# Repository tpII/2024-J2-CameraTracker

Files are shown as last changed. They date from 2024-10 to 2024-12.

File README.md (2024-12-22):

# 2024-J2-CameraTracker

---

<div align="center">
  <table>
    <tr>
      <td>GIF del Robot en Acción</td>
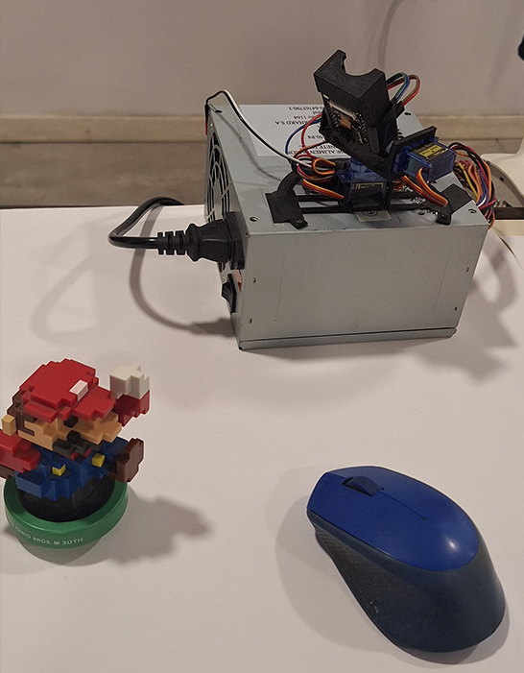
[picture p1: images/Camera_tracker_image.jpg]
Hardware del Proyecto
      <td></td>
    </tr>
  </table>
</div>

---

## Descripción

El proyecto **Camera Tracker** es un sistema de seguimiento de objetos que utiliza una cámara ESP32-CAM montada en una torreta. El sistema es capaz de reconocer y seguir objetos utilizando un modelo de aprendizaje automático optimizado, implementado en la plataforma Edge Impulse.

---

## Documentación

Consulta la [documentación del proyecto](https://github.com/tpII/2024-J2-CameraTracker/blob/master/docs/Camera%20Tracker%20-%20Project%20Overview%20%5BSP%5D.pdf) para obtener una visión más detallada de los objetivos, implementación y resultados del sistema.

---

## Contenido

- [Características](#características)
- [Hardware](#hardware)
- [Reconocimiento de Objetos](#reconocimiento-de-objetos)
- [Configuración del Entorno](#configuración-del-entorno)
- [Licencia](#licencia)

---

## Características

- Seguimiento de objetos.
- Integración de hardware utilizando ESP32-CAM y servomotores.
- Modelo de reconocimiento de objetos entrenado con Edge Impulse.
- Interfaz web para monitoreo y configuración.

---

## Hardware

El hardware del proyecto se basa en las siguientes etapas:

1. **Medición de Componentes**: Se realizan mediciones detalladas de los componentes.
2. **Diseño Inicial**: Se elabora un boceto preliminar a mano alzada.
3. **Diseño 3D**: Se utiliza Autodesk Fusion 360 para diseñar las piezas y exportarlas en formato `.stl` para impresión 3D.
4. **Prototipado**: Se desarrollan varias versiones del prototipo para optimizar el equilibrio y funcionalidad del sistema.

---

## Reconocimiento de Objetos

El reconocimiento de objetos se realiza mediante el uso de **Edge Impulse**, donde se entrena un modelo para identificar diferentes elementos. El proceso incluye:

1. **Captura de Imágenes**: Se toman aproximadamente 700 fotos de cada objeto con buena iluminación y fondo uniforme.
2. **Etiquetado**: Las imágenes se etiquetan manualmente en la plataforma Edge Impulse.
3. **Generación de Features**: Se especifica el "color depth" (escala de grises o RGB).
4. **Entrenamiento del Modelo**: Se ajusta el modelo y se realiza el entrenamiento.
5. **Evaluación**: Se utiliza la matriz de confusión para analizar el rendimiento del modelo y determinar posibles mejoras.

---

## Configuración del Entorno

### Instalación de Manejadores de Placa

1. Abre el IDE de Arduino.
2. Ve a **Archivo > Preferencias** y añade la URL para el ESP32 en "Gestor de URLs Adicionales":
   ```
   https://dl.espressif.com/dl/package_esp32_index.json
   ```
3. Dirígete a **Herramientas > Placa > Gestor de Placas** y busca e instala las siguientes versiones:
   - **Arduino AVR Boards**: Versión 1.8.6.
   - **ESP32 by Espressif Systems**: Versión 2.0.5.

### Configuración de la Placa

1. Selecciona **AI-Thinker ESP32-CAM** en el menú de placas.
2. Configura el puerto correspondiente al dispositivo conectado.

### Instalación de Bibliotecas

1. Abre el **Library Manager** desde el IDE de Arduino.
2. Instala las siguientes bibliotecas:
   - **ESP32Servo**: Versión 3.0.5.
   - **FreeRTOS** (incluida por defecto):
     ```cpp
     #include <freertos/FreeRTOS.h>
     #include <freertos/semphr.h>
     ```
   - **WiFi** y **esp_http_server** (incluidas por defecto):
     ```cpp
     #include <WiFi.h>
     #include "esp_http_server.h"
     ```
   - **Arduino Core** (incluida por defecto):
     ```cpp
     #include "Arduino.h"
     ```
3. Importa manualmente la biblioteca de inferencia generada por Edge Impulse:
   - Descarga el archivo `.zip` desde Edge Impulse.
   - Usa la opción **Sketch > Incluir Biblioteca > Añadir biblioteca .ZIP**.
   - Incluye los siguientes archivos en tu proyecto:
     ```cpp
     #include <lapor-project-1_inferencing.h>
     #include "edge-impulse-sdk/dsp/image/image.hpp"
     ```
4. Asegúrate de tener las bibliotecas para dibujado de bounding boxes:
   ```cpp
   #include "img_converters.h"
   #include "fb_gfx.h"
   ```

### Clonación del Repositorio

Clona el repositorio del proyecto para acceder a todo el código fuente y configuración:
```bash
git clone https://github.com/tpII/2024-J2-CameraTracker.git
```

---

## Licencia

Este proyecto está bajo la Licencia GPL 3.0. Consulta el archivo `LICENSE` para más detalles.

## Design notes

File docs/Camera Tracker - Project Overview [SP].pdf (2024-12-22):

# Taller de Proyecto II

## Informe Final - J2

## Camera Tracker

Grupo de Desarrollo

- Deluca, Tadeo - 02655/1
- La Porta, Franco - 02307/2
- Reverte Adriel - 02614/1

Índice

### 1. Descripción General del Proyecto

### 1.1. Introducción

El proyecto Camera Tracker se desarrolló con el objetivo de implementar un sistema de seguimiento automático de objetos mediante un ESP32-Cam y una torreta con movimiento en dos ejes. Durante las etapas iniciales y medias de desarrollo, se abordaron aspectos clave de hardware, firmware e inteligencia artificial para lograr los objetivos establecidos.

En el transcurso del desarrollo, se enfrentaron desafíos técnicos, como problemas eléctricos y fallas en componentes de hardware, que requirieron soluciones iterativas. Estos ajustes permitieron entregar un sistema funcional capaz de realizar el seguimiento de objetos para el cual fue entrenado, cumpliendo los objetivos primarios propuestos originalmente.

### 1.2. Objetivos del Proyecto

Objetivos Iniciales

El proyecto fue diseñado para cumplir los siguientes objetivos principales, los cuales fueron cumplidos::

1. Captura y transmisión de video: Implementar un sistema de streaming en vivo desde la cámara a través de una interfaz web.
2. Detección y seguimiento de objetos: Utilizar un modelo de inteligencia artificial para detectar y rastrear objetos.
3. Control de la torreta: Ajustar dos servomotores para alinear la cámara con el objeto detectado, ofreciendo movimiento en dos ejes.
4. Interacción desde la interfaz web: Permitir la selección del objeto a rastrear entre dos opciones disponibles (una estatuilla de Super Mario y un mouse azul) y activar/desactivar el streaming de video.

Cambios y Modificaciones

1. Modificaciones sugeridas por la cátedra:
- Fuente de alimentación externa: Debido a problemas de consumo eléctrico al conectar el ESP32-Cam y los dos servos, se utilizó una fuente de alimentación externa proporcionada por la cátedra. Esto solucionó los problemas de insuficiencia energética y permitió un funcionamiento estable.

2. Cambios derivados de decisiones de desarrollo:
- Reemplazo de hardware defectuoso: Se identificaron fallas en los servomotores SG90 y en el flex de la cámara del ESP32-Cam. Estas fallas llevaron a la sustitución de componentes dañados, incluyendo la compra de una nueva ESP32-Cam.
3. Modificaciones técnicas propias:
- Botones para selección de objetos: Se agregó a la interfaz web la funcionalidad para permitir al usuario seleccionar entre dos objetos predefinidos (Super Mario y el Mouse) como objetivo del seguimiento.
- Reestilizado de la interfaz web: Se realizaron mejoras visuales en la interfaz web.
- Dibujado de la bounding box: Se implementó una funcionalidad que dibuja un marcador visual (bounding box) alrededor del objeto detectado en la transmisión de video.
- Optimización de la lógica de movimiento de servos:
- Cambio en la lógica de movimiento: La lógica inicial, basada en un mapeo directo entre las coordenadas de píxeles en la imagen y los ángulos de los servos, fue reemplazada. En su lugar, se adoptó un enfoque de movimiento en pasos de ángulos discretos hacia la dirección del objeto detectado. Este cambio permitió que el movimiento fuera más suave y controlado, lo que redujo vibraciones y aumentó la precisión aparente del seguimiento.

Objetivos no Cumplidos

Los objetivos secundarios relacionados con la implementación de conexión a servicios en la nube y medidas avanzadas de seguridad (autenticación mediante formulario y protocolo HTTPS) no pudieron ser completados debido a limitaciones de tiempo y retrasos asociadas al hardware del proyecto.

### 2. Presentación Esquemática del Proyecto

En esta sección presentaremos una actualización completa del proyecto tal como se entrega.

El siguiente gráfico ilustra el flujo desde la captura de una fotografía hasta el procesamiento e inferencia de los datos obtenidos.

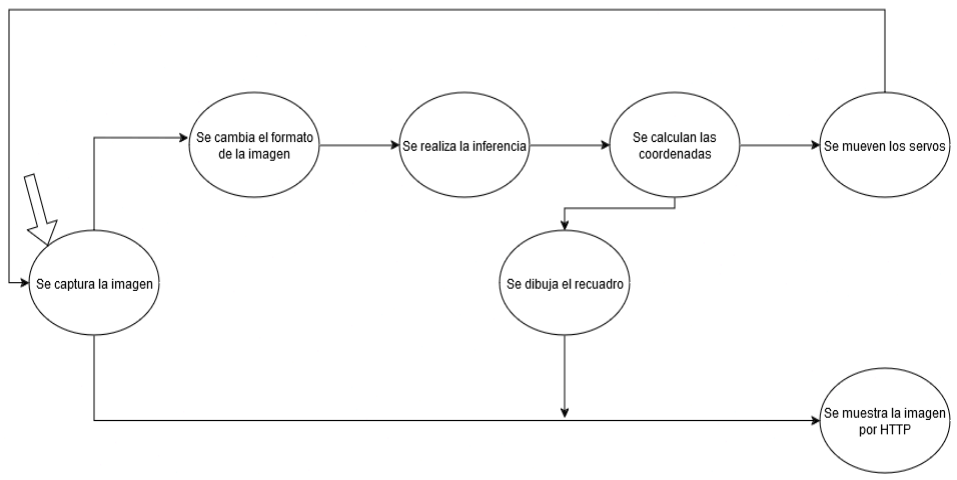
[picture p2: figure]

Figura 1. Diagrama de flujo captura de imagen

Se observa cómo la imagen capturada pasa por un cambio de formato para ser utilizada en la inferencia. Luego, si se identifica un objeto seleccionado con una confianza superior al 85%, se realiza la identificación, se marca su posición en la imagen con un recuadro, y se envían señales a los servomotores para ajustar la dirección de la cámara hacia el objeto. Finalmente, la última imagen procesada se transmite en formato JPG al servidor HTTP.

A continuación, se presenta el esquema gráfico que describe la versión estática del sistema desarrollado.

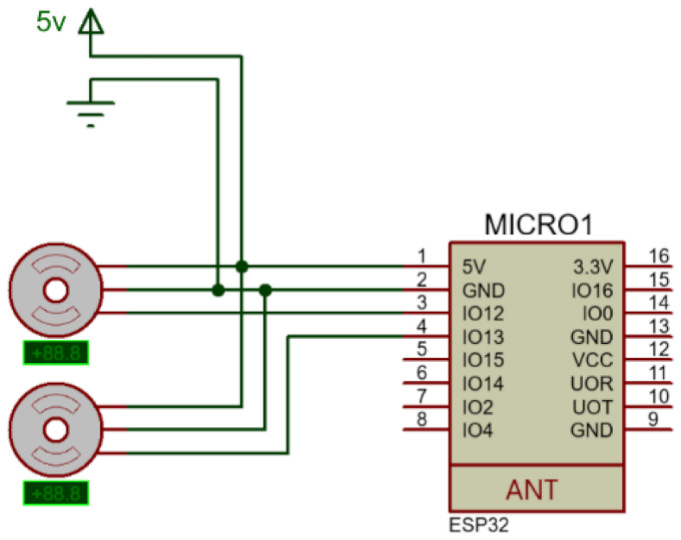
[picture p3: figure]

Figura 2. Esquema gráfico físico

En este diagrama, se identifica al ESP32-CAM como el componente principal del sistema, programado mediante un programador USB y alimentado por una fuente de computadora a través de un módulo step-down, que asegura el suministro de energía adecuado. Además, se muestra cómo el ESP32-CAM controla dos servomotores SG90, responsables de permitir el movimiento de la cámara para la función de seguimiento de objetos. Cada módulo y conexión se detalla de manera explícita para facilitar la comprensión del diseño y su implementación.

### 3. Estructura del proyecto CameraTracker

El proyecto se organiza en una estructura jerárquica que incluye los archivos principales y las librerías necesarias para implementar las funcionalidades del sistema. A continuación, se describe la estructura y el contenido de cada componente.

### 3.1. Estructura de archivos

CameraTracker/
├── CameraTracker.ino
├── camera_config.h
├── servo_control.h
├── web_server.h
└── libraries/
├── ESP32Servo
└── lapor-project-1_inferencing

### 3.2. Descripción de los archivos principales

### 1. Archivo camera_config.h

Este archivo define las configuraciones del módulo de cámara AI-Thinker ESP32-CAM, incluyendo los pines GPIO y los parámetros constantes para la captura de imágenes.

Contenido principal:

- Definición de pines GPIO utilizados por la cámara.
- Configuración de las dimensiones del búfer de imágenes capturadas.
- Inclusión de librerías esenciales como esp_camera.h y fb_gfx.h para la configuración de la cámara y manipulación de imágenes..

### 2. Archivo servo_control.h

Define los pines GPIO asociados con los servos utilizados para el control del movimiento de la cámara y emplea la librería ESP32Servo para gestionar su funcionamiento.

### 3. Archivo web_server.h

Gestiona la configuración y las funcionalidades del servidor web.

Contenido principal:

- Inclusión de librerías esenciales como WiFi.h y esp_http_server.h.
- Configuración de constantes para el manejo del flujo de transmisión, como PART_BOUNDARY.

### 4. Archivo CameraTracker.ino

Integra la lógica central del proyecto, incluyendo la inicialización de los componentes, la ejecución de las funciones principales y la interacción entre las diferentes partes del sistema.

Funciones principales:

- setup():
- Inicializa la cámara, la conexión Wi-Fi, los servos y las tareas para el streaming y la inferencia.
- Configura el servidor web.
- loop():
- Vacío debido a que las operaciones continuas son gestionadas por las tareas paralelas inferenceLoop y streamLoop.
- inferenceLoop():
- Ejecuta las inferencias sobre las imágenes capturadas.
- Ajusta la posición de los servos según los resultados de la inferencia.
- streamLoop():
- Administra el estado del servidor web y lo reinicia si es necesario.

Otras funciones relevantes

### 1. Inicialización y control de la cámara

- ei_camera_init(): Configura y activa la cámara.
- ei_camera_deinit(): Libera los recursos asociados a la cámara.

- ei_camera_capture(uint32_t img_width, uint32_t img_height, uint8_t *out_buf): Captura una imagen con las dimensiones especificadas por el modelo que realiza la inferencia y la almacena en el búfer proporcionado.

### 2. Configuración del servidor web

- startCameraServer(): Configura y lanza el servidor web para la transmisión de imágenes.
- index_handler(httpd_req_t *req): Maneja las solicitudes a la página de inicio (/) y proporciona una respuesta HTML.
- select_handler(httpd_req_t *req): Procesa solicitudes HTTP relacionadas con la selección de objetos para rastrear.
- stream_handler(httpd_req_t *req): Maneja el flujo continuo de video (streaming).

### 3. Tareas concurrentes

- inferenceLoop(void *parameter):
- Ejecuta inferencias de clasificación sobre imágenes capturadas usando un modelo de Edge Impulse.
- Ajusta la posición de los servos con base en los resultados de la inferencia.
- streamLoop(void *parameter): Supervisa el servidor web y lo reinicia si deja de funcionar.

### 3.3. Configuración de software y dependencias del proyecto

### 3.3.1. Configuración de manejadores de placa en el Arduino IDE

Manejadores de Placa Instalados

Para el desarrollo del proyecto, se instalaron los siguientes manejadores de placa a través del Board Manager del IDE de Arduino:

- Arduino AVR Boards: Versión 1.8.6, utilizada para gestionar placas basadas en microcontroladores AVR en proyectos generales.
- ESP32 by Espressif Systems: Versión 2.0.5. Esta versión fue seleccionada por su compatibilidad con las bibliotecas utilizadas en el proyecto, como la biblioteca de inferencia generada por Edge Impulse y la biblioteca WiFi.h. No se utilizó la versión más reciente debido a problemas de compatibilidad.

### 3.3.2. Configuración de la Placa

La generación y carga del binario se realizó configurando la placa como "AI-Thinker ESP32-CAM", correspondiente al módulo de hardware utilizado en el proyecto. Esta configuración fue seleccionada desde el menú de puertos del IDE, asegurando que los parámetros de hardware coincidan con los requisitos del módulo.

### 3.3.3. Bibliotecas utilizadas en el proyecto

Bibliotecas instaladas mediante el Library Manager

El proyecto requiere la instalación de bibliotecas adicionales que no están incluidas de forma nativa en el IDE de Arduino. Estas bibliotecas deben instalarse a través del Library Manager..

- ESP32Servo: Versión 3.0.5, desarrollada por Kevin Harrington. Esta biblioteca permite el control de servomotores utilizando señales PWM generadas por el ESP32.

Bibliotecas nativas utilizadas

El proyecto también emplea bibliotecas que ya están incluidas de manera predeterminada en el IDE de Arduino o que no requieren instalación adicional. Estas incluyen:

FreeRTOS
#include <freertos/FreeRTOS.h>

#include <freertos/semphr.h>

- Utilizada para la concurrencia y la gestión de tareas en el ESP32, permitiendo implementar semáforos para la sincronización entre tareas.

WiFi y esp_http_server:
#include <WiFi.h>

#include "esp_http_server.h"

- Estas bibliotecas son esenciales para la configuración y operación del servidor web.

Arduino Core:
#include "Arduino.h"

- Incluye funcionalidades básicas y esenciales para la programación y ejecución en plataformas Arduino.

Bibliotecas externas requeridas

Además de las bibliotecas mencionadas, se utilizaron otras librerías específicas que deben ser incluidas manualmente en el proyecto:

Biblioteca de Inferencia Generada por Edge Impulse:

#include <lapor-project-1_inferencing.h>

#include "edge-impulse-sdk/dsp/image/image.hpp"

- Esta biblioteca es generada al exportar el modelo desde Edge Impulse en formato compatible con el IDE de Arduino. Se importa como archivo comprimido .zip y debe ser incluida en el proyecto a través de la opción "Añadir biblioteca .ZIP" en el IDE. Permite realizar inferencias utilizando el modelo previamente entrenado.

Bibliotecas para Dibujado de la Bounding Box:

#include "img_converters.h"

#include "fb_gfx.h"

- Estas bibliotecas son necesarias para procesar y renderizar elementos gráficos, como la bounding box, sobre las imágenes capturadas.

### 3.4. Herramientas de desarrollo y control de versiones

El proyecto utilizó Git para control de versiones y GitHub como repositorio online, facilitando la colaboración y el seguimiento de cambios. El desarrollo se realizó en el Arduino IDE.

### 3.5. Caso de uso del proyecto

En el siguiente diagrama de secuencia se presenta el caso completo que ocurre cuando un usuario selecciona uno de los objetos disponibles para ser identificado. El diagrama detalla todas las etapas del proceso, comenzando desde la inicialización del servidor web, encargado de gestionar las interacciones con el sistema, hasta la creación del recuadro que destaca el objeto identificado en la imagen procesada. Además, se incluye el control y ajuste de los servomotores, que permiten al sistema ajustar dinámicamente la posición de la cámara.

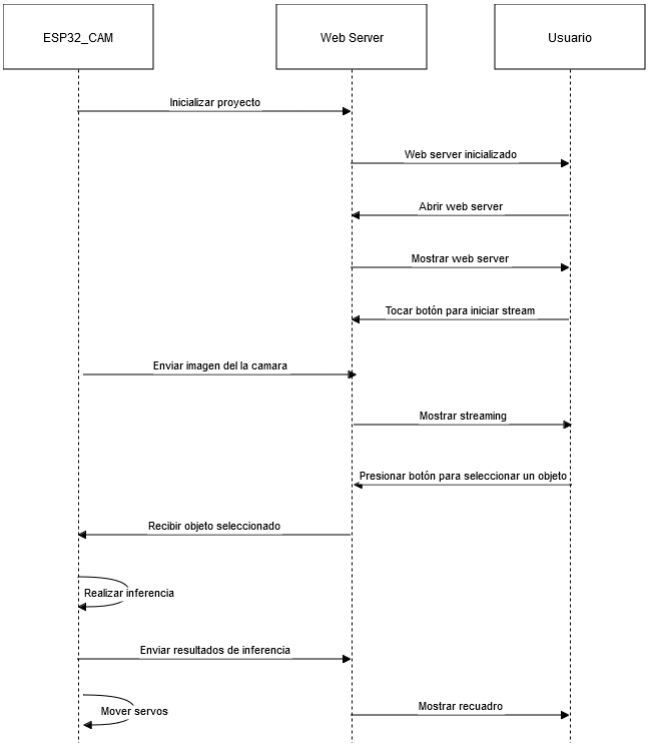
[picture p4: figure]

Figura 3. Diagrama de secuencia selección de objetos

### 4. Documentación Relacionada

### 4.1. Imágenes

En la primera imagen se muestra la interfaz web desarrollada para el proyecto, destacando las funcionalidades implementadas.

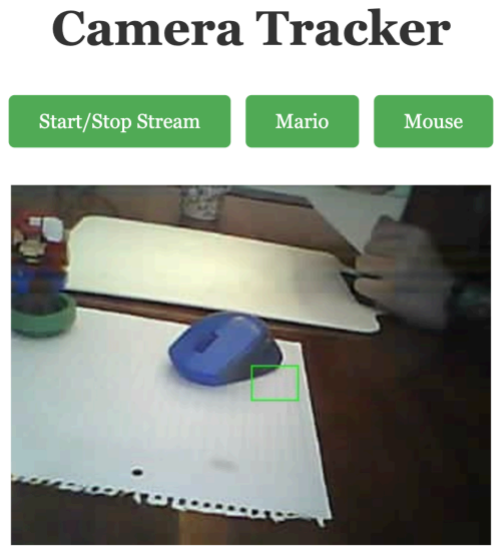
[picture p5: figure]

Figura 4. Imagen Web Server

En las siguientes imágenes se puede apreciar el aspecto físico del sistema, incluyendo la estructura completa y los servomotores encargados de controlar el movimiento de la cámara.

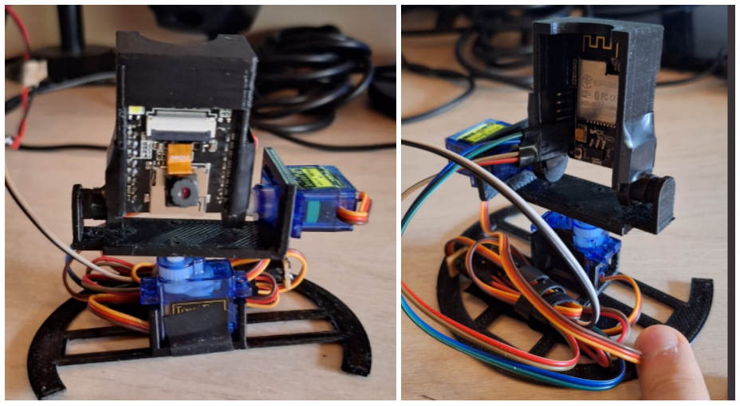
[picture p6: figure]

Figura 5. Imagen estructura con servos

### 4.2 Vídeos

Los vídeos relacionados con el proyecto están disponibles en la carpeta compartida, accesible a través del siguiente enlace: Carpeta de vídeos del proyecto (https://drive.google.com/drive/folders/1a-1BKRMfYGsX6SbaYhJ6COHhbvPWrK5T)

En el video titulado "Camera Tracker video de muestra", se presenta el proyecto en su totalidad, mostrando de manera clara y detallada su funcionamiento completo.

### 4.3 Enlaces Relevantes

- Bitácora del Proyecto: La bitácora de avances de cada integrante del grupo se encuentra actualizada hasta la fecha y está disponible en el siguiente enlace: Bitácora (https://github.com/tpII/2024-J2-CameraTracker/wiki/Bit%C3%A1cora)
- Código Fuente: El código fuente de todos los ejemplos desarrollados hasta el momento está disponible en GitHub: Repositorio en GitHub (https://github.com/tpII/2024-J2-CameraTracker)
- Carpeta Compartida del Proyecto: Todos los archivos de interés relacionados con el proyecto se encuentran en la carpeta compartida accesible a través del siguiente enlace: Carpeta del Proyecto (https://drive.google.com/drive/folders/1a-1BKRMfYGsX6SbaYhJ6COHhbvPWrK5T)

Apéndice A. Materiales y Presupuesto

En esta sección se detalla la lista completa y actualizada de los elementos de hardware necesarios para la construcción del proyecto Camera Tracker, diferenciando entre aquellos que fueron provistos por la cátedra y los que fueron adquiridos por los alumnos. Además, se incluyen los costos aproximados de cada uno de estos materiales, basados en precios obtenidos durante el período de desarrollo del proyecto. Cabe aclarar que no se consideran dentro de este presupuesto dispositivos adicionales como computadoras o teléfonos móviles.

### 1. Materiales Provistos por la Cátedra

La cátedra ha proporcionado varios componentes esenciales para la realización del proyecto, los cuales se detallan a continuación:

- ESP32-Cam + Programador: $19.980,90
Esp32 Cam Ov2640 + Placa Base Programador Esp32-cam-mb Hobb | MercadoLibre (https://articulo.mercadolibre.com.ar/MLA-1138395462-esp32-cam-ov2640-placa-base-programador-esp32-cam-mb-hobb-_JM)
- Servo SG90 (x2): $2.519 (c/u)
Mini Servo Tower Pro Sg90 9g Robotica Arduino Servomotor | MercadoLibre (https://articulo.mercadolibre.com.ar/MLA-903024303-mini-servo-tower-pro-sg90-9g-robotica-arduino-servomotor-_JM)
- Fuente de PC: $19.500,00
Lote 2 Fuentes Atx 24p+p4 400w 450w Usadas Garantia Congreso | MercadoLibre (https://articulo.mercadolibre.com.ar/MLA-934999936-lote-2-fuentes-atx-24pp4-400w-450w-usadas-garantia-congreso-_JM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)

Estos materiales fueron claves para la implementación inicial del sistema de seguimiento, especialmente para el control de la cámara y la alimentación de la misma.

### 2. Materiales Provistos por los Alumnos

A continuación, se detallan los materiales adquiridos directamente por los alumnos para complementar el proyecto, los cuales también fueron necesarios para el montaje y pruebas del sistema:

- Protoboard: $4.000,00
Placa Experimental Protoboard 830 Puntos Arduino Electronica | MercadoLibre (https://www.mercadolibre.com.ar/placa-experimental-protoboard-830-puntos-arduino-electronica/p/MLA27915857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)
- Cables Arduino:
Cables Para Protoboard Macho Macho 20 Cm X 40 Dupont Arduino | MercadoLibre (https://www.mercadolibre.com.ar/cables-para-protoboard-macho-macho-20-cm-x-40-dupont-arduino/p/MLA32489698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)
- Filamento PLA: $12.999,00
Filamento Pla Impresora 3d * G S T * 1,75mm 320mt X1 Kg Gst | MercadoLibre (https://articulo.mercadolibre.com.ar/MLA-829117078-filamento-pla-impresora-3d-g-s-t-175mm-320mt-x1-kg-gst-_JM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)
- Cable USB Micro: $2.798,00
Cable Usb Somostec Micro Trenzado Carga Rápida 3.1 A 1m F | MercadoLibre (https://articulo.mercadolibre.com.ar/MLA-1600964172-cable-usb-somostec-micro-trenzado-carga-rapida-31-a-1m-f-_JM)

### 3. Evaluación de Presupuesto y Materiales

En general, la mayoría de los materiales esenciales para la construcción y prueba del Camera Tracker fueron provistos por la cátedra, con excepción de algunos componentes auxiliares que fueron adquiridos por los alumnos. Aunque algunos materiales ya se encuentran disponibles, las pruebas y desarrollo del proyecto dependerá de la correcta implementación de estos y otros materiales que puedan ser necesarios a futuro.

La suma total de los componentes adquiridos hasta el momento asciende a:

- Materiales provistos por la cátedra: $44.520
- Materiales adquiridos por los alumnos: $19.800

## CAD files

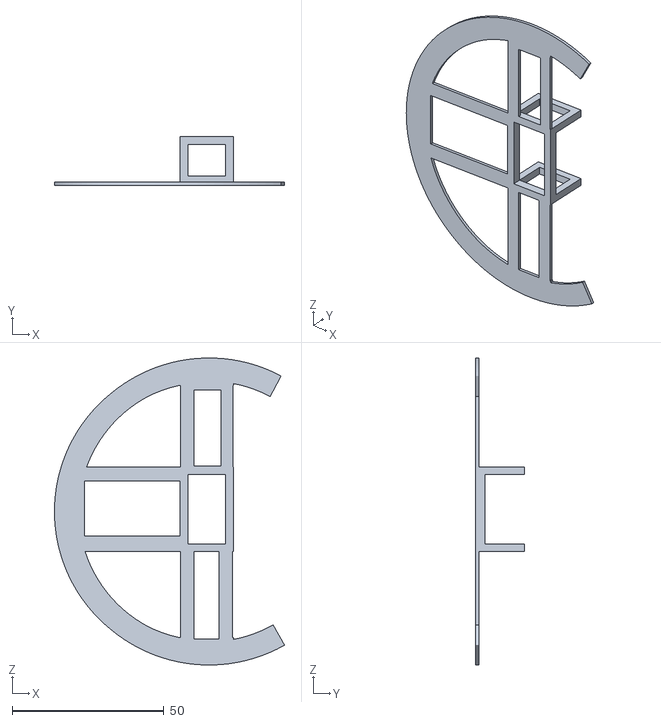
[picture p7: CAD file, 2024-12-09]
Diseños 3D/Estructura Final/Base.stl
75.9 x 16.0 x 101.3

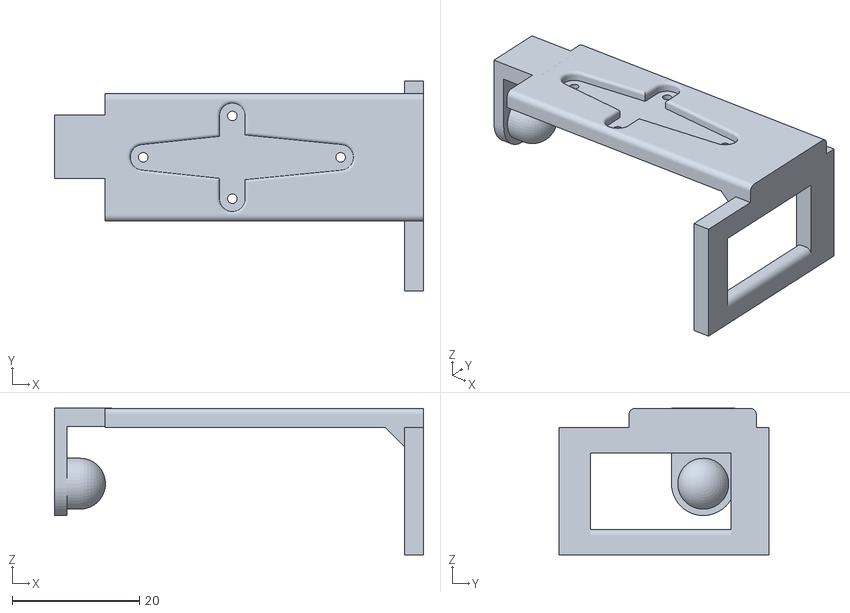
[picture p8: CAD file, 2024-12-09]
Diseños 3D/STLs/v7/Servo 5 v22.stl
57.9 x 33.0 x 23.0

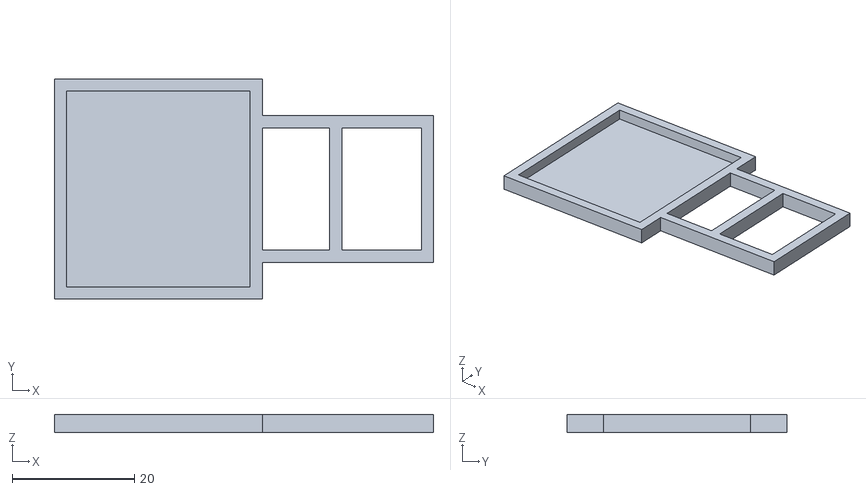
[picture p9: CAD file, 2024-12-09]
Diseños 3D/STLs/v6 (base)/base prueba.stl
62.0 x 36.0 x 3.00

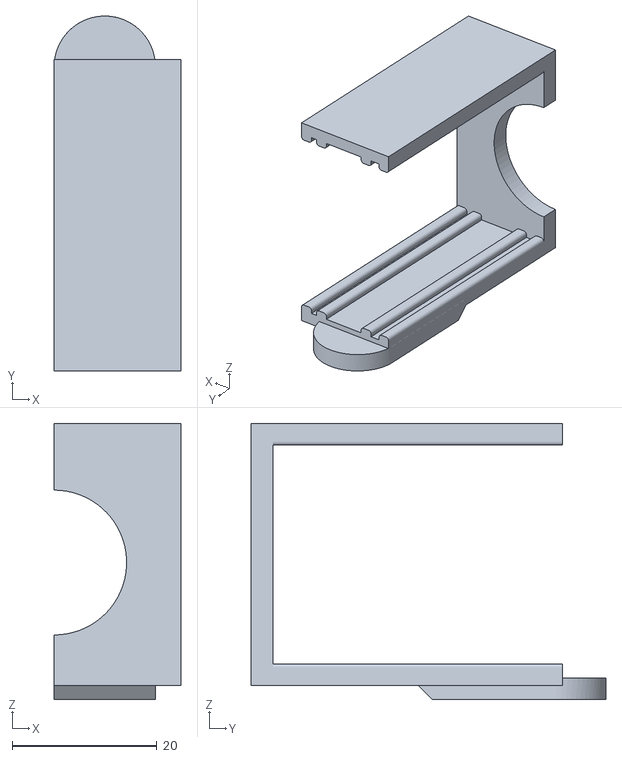
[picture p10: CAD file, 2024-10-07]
Diseños 3D/Estructura Final/pieza A.stl
17.5 x 49.0 x 38.1

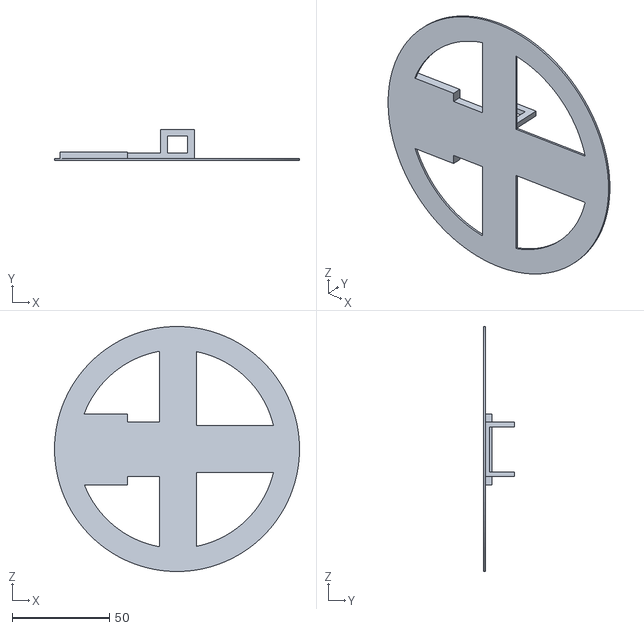
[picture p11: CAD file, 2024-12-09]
Diseños 3D/STLs/v6 (base)/base v16.stl
125.8 x 16.0 x 125.9

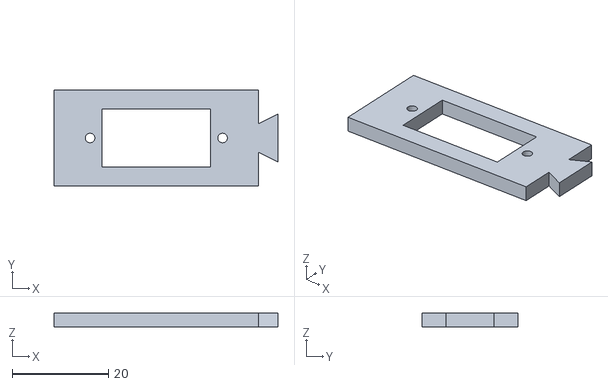
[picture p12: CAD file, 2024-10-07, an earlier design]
Diseños 3D/STLs/v1/Servo 1 v4.stl
46.5 x 20.0 x 3.00

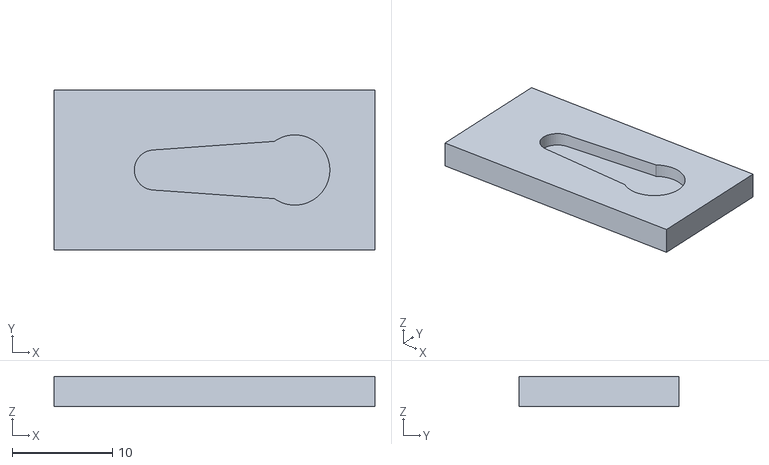
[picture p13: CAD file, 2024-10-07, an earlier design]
Diseños 3D/STLs/v2/Servo 4 v4.stl
32.0 x 16.0 x 3.00

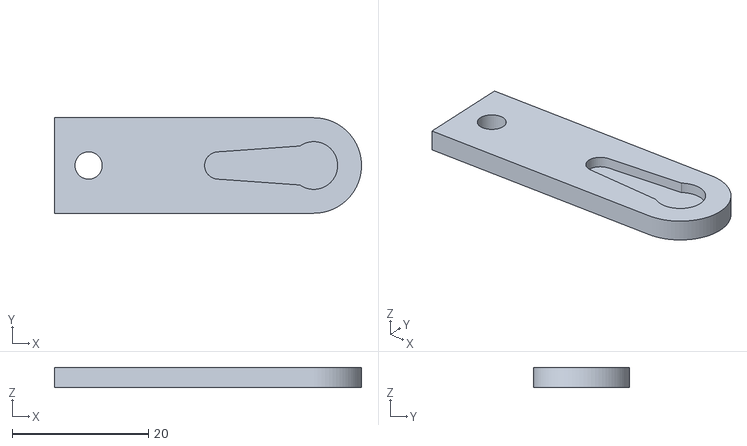
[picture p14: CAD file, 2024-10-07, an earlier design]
Diseños 3D/STLs/v3/Servo 4 v7.stl
45.0 x 14.0 x 3.00

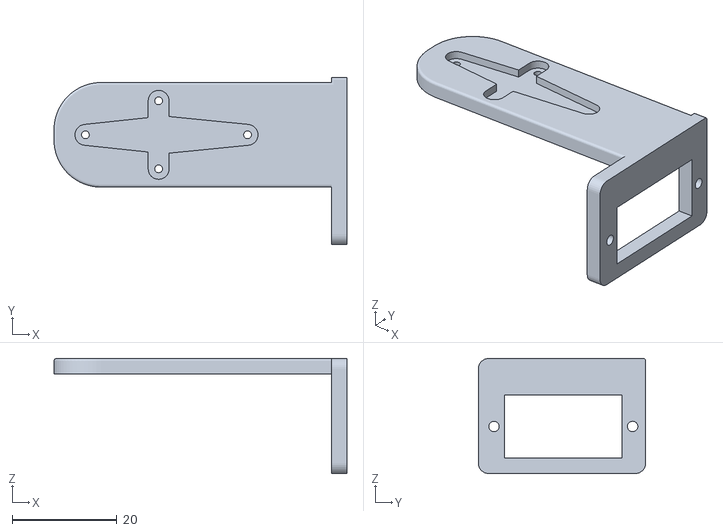
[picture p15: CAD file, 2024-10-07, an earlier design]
Diseños 3D/STLs/v4/Servo 5 v9.stl
56.0 x 32.0 x 22.0

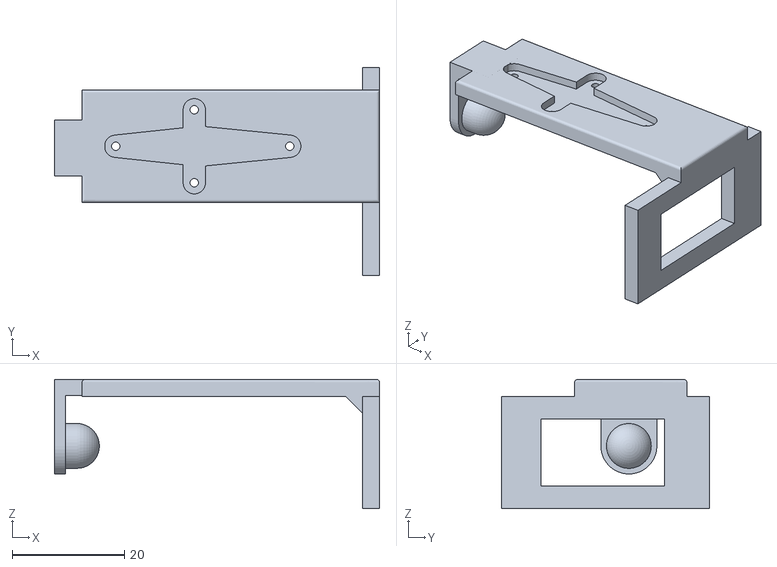
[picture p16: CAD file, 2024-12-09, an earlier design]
Diseños 3D/STLs/v5/Servo 5 v18.stl
57.9 x 37.0 x 23.0

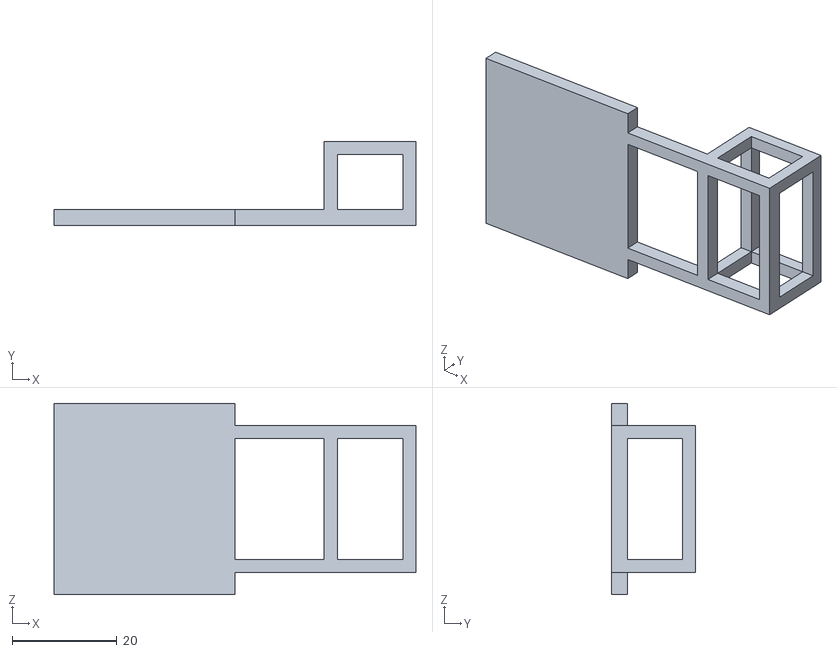
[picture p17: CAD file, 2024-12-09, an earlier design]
Diseños 3D/STLs/v6 (base)/base v9.stl
69.0 x 16.0 x 36.5

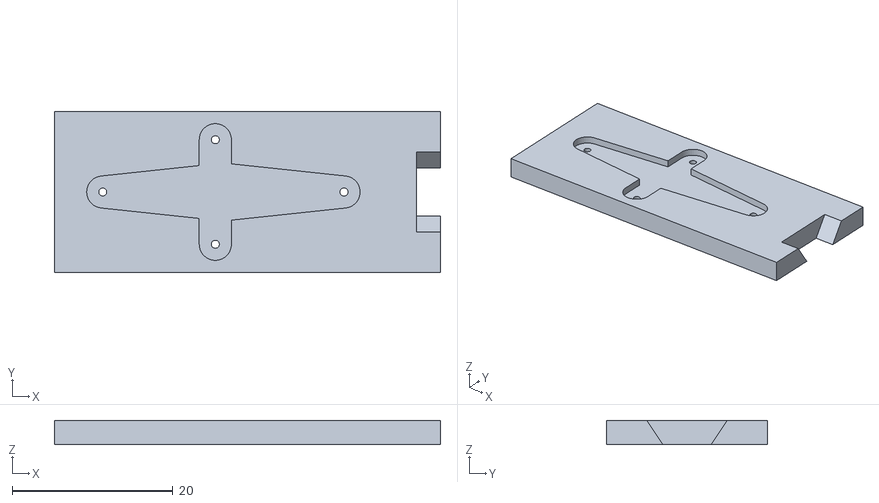
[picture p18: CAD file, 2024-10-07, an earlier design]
Diseños 3D/STLs/v1/Servo 2 v11.stl
48.0 x 20.0 x 3.00

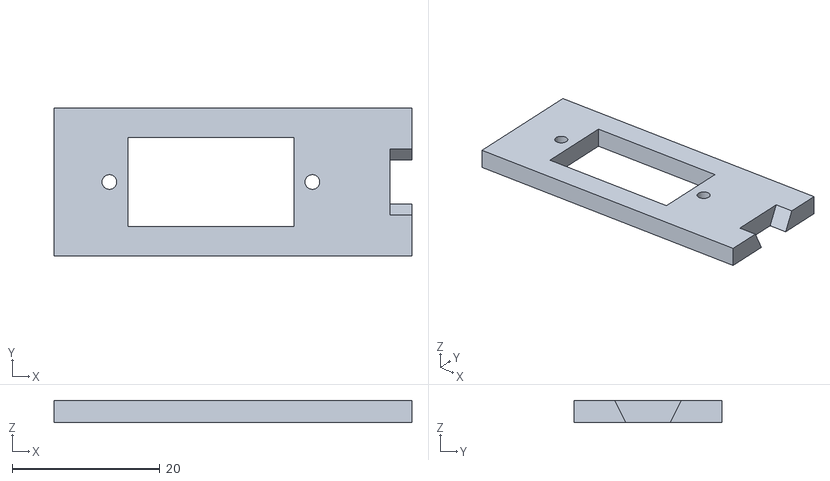
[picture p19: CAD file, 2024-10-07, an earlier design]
Diseños 3D/STLs/v2/Servo 3 v1.stl
48.5 x 20.0 x 3.00

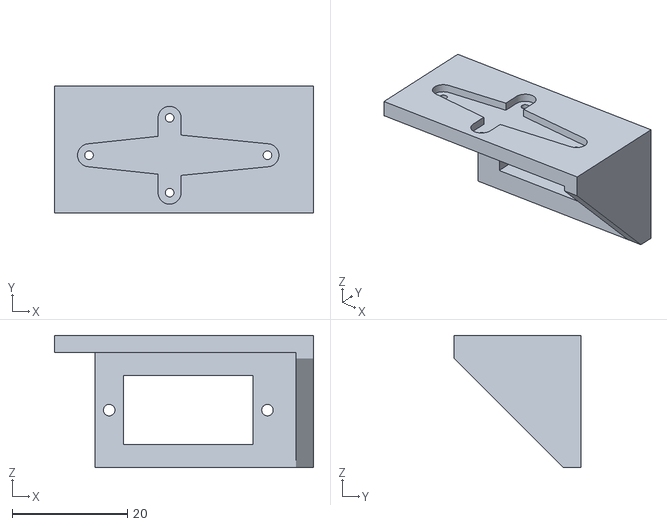
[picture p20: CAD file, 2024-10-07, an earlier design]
Diseños 3D/STLs/v3/Servo 6 v6.stl
45.0 x 22.0 x 23.0

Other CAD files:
Diseños 3D/STLs/v7/base v21.stl
Diseños 3D/STLs/v2/Servo 2 v16.stl
Diseños 3D/STLs/v3/Cam sosten v9.stl
Diseños 3D/STLs/v3/cil.stl
Diseños 3D/STLs/v6 (base)/base v10.stl
Diseños 3D/STLs/v7/base v22.stl

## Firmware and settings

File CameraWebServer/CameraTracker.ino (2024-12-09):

// Edge Impulse
#include <lapor-project-1_inferencing.h>
#include "edge-impulse-sdk/dsp/image/image.hpp"

#include "camera_config.h"
#include "web_server.h"
#include "servo_control.h"

#include <freertos/FreeRTOS.h>
#include <freertos/semphr.h> // Include FreeRTOS semaphore header

static const char* _STREAM_CONTENT_TYPE = "multipart/x-mixed-replace;boundary=" PART_BOUNDARY;
static const char* _STREAM_BOUNDARY = "\r\n--" PART_BOUNDARY "\r\n";
static const char* _STREAM_PART = "Content-Type: image/jpeg\r\nContent-Length: %u\r\n\r\n";

// Credenciales Wi-Fi
const char *ssid = "alumnosInfo";
const char *password = "InformaticaUNLP";

/* Private variables ------------------------------------------------------- */
static bool debug_nn = false;
static bool is_initialised = false;

// Pointer to buffer that holds captured image data
uint8_t *snapshot_buf;

// Calculate the scaling factors based on the new dimensions
float scaleX = (float)EI_CAMERA_RAW_FRAME_BUFFER_COLS / 80;
float scaleY = (float)EI_CAMERA_RAW_FRAME_BUFFER_ROWS / 80;

/* Function definitions ------------------------------------------------------- */
bool ei_camera_init(void);
void ei_camera_deinit(void);
bool ei_camera_capture(uint32_t img_width, uint32_t img_height, uint8_t *out_buf);

/* Web server functions prototypes -------------------------------------------- */
void startCameraServer(void);
static esp_err_t index_handler(httpd_req_t *req);
static esp_err_t select_handler(httpd_req_t *req);
static esp_err_t stream_handler(httpd_req_t *req);

//WEB SERVER
httpd_handle_t stream_httpd = NULL;
camera_fb_t * fb = NULL;
String selectedObject = "None"; // Variable to store the selected object

// Servos
Servo s1;
Servo s2;
int servoPosX = 90;
int servoPosY = 90;
enum MovServo {anda, nada};
enum MovServo cualServo = nada;

int cx, cy;
int x, y, w, h;
float max_value = 0.6;
#define COLOR_GREEN  0x0000FF00
uint32_t green_color = COLOR_GREEN;

// Add these for task handling
TaskHandle_t inferenceTask;
TaskHandle_t streamTask;

// Function declarations for tasks
void inferenceLoop(void * parameter);
void streamLoop(void * parameter);

// Add this global variable at the top with other globals
bool serverStarted = false;

// Add this line to declare a mutex
SemaphoreHandle_t fbMutex;

/**
* @brief      Arduino setup function
*/
void setup() {
  WRITE_PERI_REG(RTC_CNTL_BROWN_OUT_REG, 0); // Disable brownout detector
 
  Serial.begin(115200);
  Serial.setDebugOutput(false);

  // Initialize servos
  s1.attach(S1_PIN);
  s2.attach(S2_PIN);
  //Posicion default Servos
  s1.write(servoPosX);
  s2.write(servoPosY);
  vTaskDelay(1000);

  // Initialize EI camera
  if (ei_camera_init() == false) {
      ei_printf("Failed to initialize Camera!\r\n");
  }
  else {
      ei_printf("Camera initialized\r\n");
  }
  
  // Wi-Fi connection
  WiFi.begin(ssid, password);

  while (WiFi.status() != WL_CONNECTED) {
    delay(500);
    Serial.print(".");
  }

  Serial.println("WiFi connected");
  
  Serial.print("Camera Stream Ready! Go to: http://");
  Serial.println(WiFi.localIP());

  // Create the mutex
  fbMutex = xSemaphoreCreateMutex();
  
  // Start streaming web server
  startCameraServer();
  ei_printf("\r\nStarting continious inference in 2 seconds...\r\n");  
  ei_sleep(2000);

  // Create tasks for different cores
  xTaskCreatePinnedToCore(
      inferenceLoop,    // Task function
      "InferenceTask",  // Name
      10000,           // Stack size
      NULL,            // Parameters
      1,              // Priority
      &inferenceTask, // Task handle
      0              // Core ID (0)
  );

  xTaskCreatePinnedToCore(
      streamLoop,     // Task function
      "StreamTask",   // Name
      10000,         // Stack size
      NULL,          // Parameters
      1,             // Priority
      &streamTask,   // Task handle
      1             // Core ID (1)
  );  
}

void loop() {
    // Empty - tasks handle the work
    vTaskDelay(1000);
}

// New task function for inference
void inferenceLoop(void * parameter) {
    Serial.print("Inference task running on core: ");
    Serial.println(xPortGetCoreID());
    
    while(true) {

        if (xSemaphoreTake(fbMutex, portMAX_DELAY) == pdTRUE)  {

          max_value = 0.85;
            // instead of wait_ms, we'll wait on the signal, this allows threads to cancel us...
          if (ei_sleep(5) != EI_IMPULSE_OK) {            
              vTaskDelay(500);
              xSemaphoreGive(fbMutex);       
              return;
          }
        
          // Allocate snapshot buffer
          snapshot_buf = (uint8_t*)malloc(EI_CAMERA_RAW_FRAME_BUFFER_COLS * EI_CAMERA_RAW_FRAME_BUFFER_ROWS * EI_CAMERA_FRAME_BYTE_SIZE);

          // Check if allocation was successful
          if(snapshot_buf == nullptr) {
              ei_printf("ERR: Failed to allocate snapshot buffer!\n");
              free(snapshot_buf);
              xSemaphoreGive(fbMutex);
              vTaskDelay(500);
              return;
          }

          // Save frame buffer (fb) on the snapshot
          if (ei_camera_capture((size_t)EI_CLASSIFIER_INPUT_WIDTH, (size_t)EI_CLASSIFIER_INPUT_HEIGHT, snapshot_buf) == false) {
              ei_printf("Failed to capture image on inference\r\n");
              free(snapshot_buf);
              xSemaphoreGive(fbMutex);
              vTaskDelay(500);
              return;
          }

          ei::signal_t signal;
          signal.total_length = EI_CLASSIFIER_INPUT_WIDTH * EI_CLASSIFIER_INPUT_HEIGHT;
          signal.get_data = &ei_camera_get_data;

          ei_impulse_result_t result = { 0 };

          EI_IMPULSE_ERROR err = run_classifier(&signal, &result, debug_nn);
          if (err != EI_IMPULSE_OK) {
              ei_printf("ERR: Failed to run classifier (%d)\n", err);
              xSemaphoreGive(fbMutex);
              free(snapshot_buf);
              vTaskDelay(500);
              return;
          }

          free(snapshot_buf);

          if (fb)
          {
              esp_camera_fb_return(fb);
          }

          xSemaphoreGive(fbMutex);
          
          for (uint32_t i = 0; i < result.bounding_boxes_count; i++) {
              ei_impulse_result_bounding_box_t bb = result.bounding_boxes[i];

              // Solo continuar si la etiqueta coincide con el objeto seleccionado              
              if (String(bb.label) != selectedObject) {
                  continue;
              }

              if (bb.value <= 0.85) {
                  continue;
              }

              ei_printf("  %s (%f) [ x: %u, y: %u, width: %u, height: %u ]\r\n",
                      bb.label,
                      bb.value,
                      bb.x,
                      bb.y,
                      bb.width,
                      bb.height);

              if (bb.value > max_value) {                
                max_value = bb.value;
                // Convert bounding box coordinates to the new dimensions
                x = (int)(bb.x * scaleX);
                y = (int)(bb.y * scaleY);
                w = (int)(bb.width * scaleX);
                h = (int)(bb.height * scaleY);
                
                cx = bb.x + bb.width/2;
                cy = bb.y + bb.height/2;

                cualServo = anda;
              }                            
          }

          if (cualServo == anda) {
            if(cx <= 32){
              servoPosX += 2; 
            } else if (cx >= 48){
              servoPosX -= 2;
            }            

            if(servoPosX < 0) servoPosX = 0;
            if(servoPosX > 180) servoPosX = 180;

            s2.write(servoPosX);            
            
            if (cy <= 32) {
              servoPosY += 2;
            } else if (cy >= 48) {
              servoPosY -= 2;
            }

            if(servoPosY < 45) servoPosY = 45;
            if(servoPosY > 135) servoPosY = 135;

            s1.write(servoPosY);
            
            cualServo = nada;
          }          
        }
    }
}

// New task function for streaming
void streamLoop(void * parameter) {
    Serial.print("Stream task running on core: ");
    Serial.println(xPortGetCoreID());
    
    while(true) {
        if(!serverStarted) {
            Serial.println("Starting camera server...");
            startCameraServer();
            if(stream_httpd != NULL) {
                serverStarted = true;
                Serial.println("Camera server started successfully");
            } else {
                Serial.println("Failed to start camera server");
                vTaskDelay(5000); // Wait 5 seconds before trying again
            }
        }
        vTaskDelay(1000); // Longer delay since we only need to check occasionally
    }
}

//EDGE IMPULSE
/**
 * @brief   Setup image sensor & start streaming
 *
 * @retval  false if initialisation failed
 */
bool ei_camera_init(void) {

    if (is_initialised) 
        return true;

    camera_config_t config;
    config.ledc_channel = LEDC_CHANNEL_0;
    config.ledc_timer = LEDC_TIMER_0;
    config.pin_d0 = Y2_GPIO_NUM;
    config.pin_d1 = Y3_GPIO_NUM;
    config.pin_d2 = Y4_GPIO_NUM;
    config.pin_d3 = Y5_GPIO_NUM;
    config.pin_d4 = Y6_GPIO_NUM;
    config.pin_d5 = Y7_GPIO_NUM;
    config.pin_d6 = Y8_GPIO_NUM;
    config.pin_d7 = Y9_GPIO_NUM;
    config.pin_xclk = XCLK_GPIO_NUM;
    config.pin_pclk = PCLK_GPIO_NUM;
    config.pin_vsync = VSYNC_GPIO_NUM;
    config.pin_href = HREF_GPIO_NUM;
    config.pin_sscb_sda = SIOD_GPIO_NUM;
    config.pin_sscb_scl = SIOC_GPIO_NUM;
    config.pin_pwdn = PWDN_GPIO_NUM;
    config.pin_reset = RESET_GPIO_NUM;
    config.xclk_freq_hz = 20000000;
    config.pixel_format = PIXFORMAT_JPEG;
    config.fb_location = CAMERA_FB_IN_PSRAM;
    config.grab_mode = CAMERA_GRAB_WHEN_EMPTY;
    config.ledc_timer = LEDC_TIMER_0;
    config.ledc_channel = LEDC_CHANNEL_0;

    config.frame_size = FRAMESIZE_QVGA;//FRAMESIZE_UXGA;
    config.jpeg_quality = 12;
    config.fb_count = 2;

    //initialize the camera
    esp_err_t err = esp_camera_init(&config);
    if (err != ESP_OK) {
      Serial.printf("Camera init failed with error 0x%x\n", err);
      return false;
    }

    sensor_t * s = esp_camera_sensor_get();
    // initial sensors are flipped vertically and colors are a bit saturated
    //s->set_vflip(s, 1); // flip it back

    is_initialised = true;
    return true;
}

/**
 * @brief Stop streaming of sensor data
 */
void ei_camera_deinit(void) {

    //deinitialize the camera
    esp_err_t err = esp_camera_deinit();

    if (err != ESP_OK)
    {
        ei_printf("Camera deinit failed\n");
        return;
    }

    is_initialised = false;
    return;
}


/**
 * @brief      Gets image from the frame buffer and update the snapshot buffer
 *
 * @param[in]  img_width   Width of the target image
 * @param[in]  img_height  Height of the target image  
 * @param[out] out_buf     Output buffer for the processed image
 *
 * @retval     true        Success
 * @retval     false       Failure
 *
 */
bool ei_camera_capture(uint32_t img_width, uint32_t img_height, uint8_t *out_buf) {
    if (!is_initialised) {
        ei_printf("ERR: Camera is not initialized\r\n");
        return false;
    }

    fb = esp_camera_fb_get();

    if (!fb) {
        ei_printf("Camera capture failed on ei_camera_capture\n");
        return false;
    }

    bool converted = fmt2rgb888(fb->buf, fb->len, PIXFORMAT_JPEG, out_buf);

    if(!converted){
        ei_printf("Conversion failed\n");
        return false;
    }

    ei::image::processing::crop_and_interpolate_rgb888(
      out_buf,
      EI_CAMERA_RAW_FRAME_BUFFER_COLS,
      EI_CAMERA_RAW_FRAME_BUFFER_ROWS,
      out_buf,
      img_width,
      img_height);

    return true;
}

/**
 * @brief      Get snapshot buffer of the image and convert to RGB888 format
 *
 * @param[in]  offset    Position in the image buffer to start reading from
 * @param[in]  length    Number of pixels to process
 * @param[out] out_ptr   Pointer to store the processed pixel data
 *
 * @retval     0         Success
 * 
 * @details    This function reads RGB888 data from the snapshot buffer starting at the 
 *             specified offset. It processes 'length' number of pixels, converting each 
 *             pixel from BGR to RGB format (due to ESP32-CAM hardware quirk) and stores 
 *             them as 32-bit values in the output buffer. Each pixel is packed as:
 *             (R << 16) + (G << 8) + B
 */
static int ei_camera_get_data(size_t offset, size_t length, float *out_ptr)
{
    // we already have a RGB888 buffer, so recalculate offset into pixel index
    size_t pixel_ix = offset * 3;
    size_t pixels_left = length;
    size_t out_ptr_ix = 0;

    while (pixels_left != 0) {
        // Swap BGR to RGB here
        // due to https://github.com/espressif/esp32-camera/issues/379
        out_ptr[out_ptr_ix] = (snapshot_buf[pixel_ix + 2] << 16) + (snapshot_buf[pixel_ix + 1] << 8) + snapshot_buf[pixel_ix];

        // go to the next pixel
        out_ptr_ix++;
        pixel_ix+=3;
        pixels_left--;
    }

    return 0;
}

/**
 * @brief Initializes and starts the camera server for streaming
 *
 * This function sets up an HTTP server to handle camera streaming requests.
 * It configures the server, defines URI handlers for the index page and
 * the video stream, and starts the server if initialization is successful.
 *
 * @return This function does not return a value.
 */
void startCameraServer() {
    if(stream_httpd != NULL) {
        Serial.println("Server is already running");
        return;
    }

    httpd_config_t config = HTTPD_DEFAULT_CONFIG();
    config.server_port = 80;
    config.ctrl_port = 32768;
    config.max_resp_headers = 16;
    config.recv_wait_timeout = 15;          // Tiempo de espera para recibir datos (en segundos)
    config.send_wait_timeout = 15;          // Tiempo de espera para enviar datos (en segundos)
    config.lru_purge_enable = false;        // Deshabilitar purga LRU para mantener conexiones activas
    Serial.println("Starting web server on port: 80");

    httpd_uri_t index_uri = {
        .uri       = "/",
        .method    = HTTP_GET,
        .handler   = index_handler,
        .user_ctx  = NULL
    };

    httpd_uri_t stream_uri = {
        .uri       = "/stream",
        .method    = HTTP_GET,
        .handler   = stream_handler,
        .user_ctx  = NULL
    };

    httpd_uri_t uri_select = {
      .uri       = "/select",
      .method    = HTTP_GET,
      .handler   = select_handler,
      .user_ctx  = NULL
    };

    if (httpd_start(&stream_httpd, &config) == ESP_OK) {
        httpd_register_uri_handler(stream_httpd, &index_uri);
        httpd_register_uri_handler(stream_httpd, &uri_select);
        httpd_register_uri_handler(stream_httpd, &stream_uri);
        Serial.println("HTTP server started");
    } else {
        Serial.println("Error starting HTTP server");
        stream_httpd = NULL;
    }
}

static esp_err_t index_handler(httpd_req_t *req) {
    const char* html = "<!DOCTYPE html>"
"<html><head>"
"<meta name='viewport' content='width=device-width, initial-scale=1'>"
"<title>Camera Tracker</title>"
"<style>"
"body { font-family: Georgia, serif; margin: 0; padding: 20px; text-align: center; }"
"h1 { color: #333; }"
".stream-container { position: relative; display: inline-block; }"
"#stream { max-width: 100%; height: auto; }"
".controls { margin: 20px 0; }"
"button { "
"   background-color: #4CAF50; color: white; border: none; "
"   padding: 10px 20px; margin: 5px; cursor: pointer; "
"   border-radius: 4px; font-family: Georgia, serif; "
"}"
"button:hover { background-color: #45a049; }"
"</style>"
"</head><body>"
"<h1>Camera Tracker</h1>"
"<div class='controls'>"
"<button onclick='toggleStream()'>Start/Stop Stream</button>"
"<button onclick='selectOption(\"Mario\")'>Mario</button>"
"<button onclick='selectOption(\"mouse\")'>Mouse</button>"
"</div>"
"<div class='stream-container'>"
"<img id='stream' src='/stream' alt='Camera Stream'>"
"</div>"
"<script>"
"let isStreaming = true;"
"const stream = document.getElementById('stream');"
"function toggleStream() {"
"   if (stream.style.display === 'none') {"
"       stream.style.display = 'block';"
"   } else {"
"       stream.style.display = 'none';"
"       stream.src = '';"
"       setTimeout(() => { stream.src = '/stream'; }, 100);"
"   }"
"}"
"function selectOption(option) {"
"   fetch(`/select?object=${option}`)"
"       .then(response => {"
"           if (!response.ok) {"
"               throw new Error('Network response was not ok');"
"           }"
"           return response.text();"
"       })"
"       .then(data => {"
"           console.log('Option selected:', data);"
"       })"
"       .catch(error => {"
"           console.error('Error selecting option:', error);"
"       });"
"   const stream = document.getElementById('stream');"
"   if (stream.style.display === 'none') {"
"       stream.style.display = 'block';"
"   } else {"
"       stream.style.display = 'none';"
"       stream.src = '';"
"       setTimeout(() => { stream.src = '/stream'; }, 50);"
"   }"
"   if (stream.style.display === 'none') {"
"       stream.style.display = 'block';"
"   } else {"
"       stream.style.display = 'none';"
"       stream.src = '';"
"       setTimeout(() => { stream.src = '/stream'; }, 50);"
"   }"
"}"
"</script>"
"</body></html>";


    httpd_resp_send(req, html, strlen(html));
    return ESP_OK;
}

static esp_err_t select_handler(httpd_req_t *req) {
    char query[32];
    if (httpd_req_get_url_query_str(req, query, sizeof(query)) == ESP_OK) {        
        char objectName[16];
        if (httpd_query_key_value(query, "object", objectName, sizeof(objectName)) == ESP_OK) {
            selectedObject = String(objectName); // Update the global variable
            Serial.println("Selected Object: " + selectedObject); // Print to Serial Monitor
        }
    }

    const char* response = "Object selection received.";
    httpd_resp_send(req, response, strlen(response));
    return ESP_OK;
}

static void draw_face_boxes(fb_data_t *fb, int x, int y, int w, int h)
{
    if(fb->bytes_per_pixel == 2){
        green_color = ((green_color >> 16) & 0x001F) | ((green_color >> 3) & 0x07E0) | ((green_color << 8) & 0xF800);
    }

    fb_gfx_drawFastHLine(fb, x, y, w, green_color);
    fb_gfx_drawFastHLine(fb, x, y + h - 1, w, green_color);
    fb_gfx_drawFastVLine(fb, x, y, h, green_color);
    fb_gfx_drawFastVLine(fb, x + w - 1, y, h, green_color);
}
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

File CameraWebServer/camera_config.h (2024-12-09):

#include "esp_camera.h"
#include "fb_gfx.h"
#define CAMERA_MODEL_AI_THINKER

// Camera pins
#define PWDN_GPIO_NUM     32
#define RESET_GPIO_NUM    -1
#define XCLK_GPIO_NUM      0
#define SIOD_GPIO_NUM     26
#define SIOC_GPIO_NUM     27
#define Y9_GPIO_NUM       35
#define Y8_GPIO_NUM       34
#define Y7_GPIO_NUM       39
#define Y6_GPIO_NUM       36
#define Y5_GPIO_NUM       21
#define Y4_GPIO_NUM       19
#define Y3_GPIO_NUM       18
#define Y2_GPIO_NUM        5
#define VSYNC_GPIO_NUM    25
#define HREF_GPIO_NUM     23
#define PCLK_GPIO_NUM     22

// Camera constants
#define EI_CAMERA_RAW_FRAME_BUFFER_COLS           320
#define EI_CAMERA_RAW_FRAME_BUFFER_ROWS           240
#define EI_CAMERA_FRAME_BYTE_SIZE                 3

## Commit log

2024-10-07 Codigos de prueba + Codigo del Servidor web de ejemplo
    [partitions.csv]
2024-10-07 Diseños 3D en .stl de la estructura
    [Cam sosten v9.stl, Parte arriba v5.stl, Servo 1 v4.stl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]
2024-11-03 Server WEB CAMERA c/ Edge Impulse. ESP32
2024-12-09 diseños 3d ultima fase
    [Servo 5 v18.stl, base prueba.stl, base v10.stl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]
2024-12-09 Estructura final
    [Base.stl, Servo 5 v22.stl, base prueba.stl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]
2024-12-09 Codigos de prueba nuevos
    [partitions.csv]
2024-12-09 Actualización del Código
    [partitions.csv]
